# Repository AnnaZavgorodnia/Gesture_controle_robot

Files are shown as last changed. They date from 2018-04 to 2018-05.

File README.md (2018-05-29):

# [Gesture_controle_robot](https://docs.google.com/document/d/1Y3_o9-OHFA1TtbafuHDtEz-drBp5un7FaggCU-9pLuw/edit)

  [Presentation Demo](https://docs.google.com/presentation/d/1enwyCBrnziEQhG71OeViNuP6OWcIG7AhS4pcQQWysCI/edit#slide=id.p13)
=======
  
  [Sprint #1](https://docs.google.com/presentation/d/1gFuyWH_bSRb89d4ghf7KW_kzOMq5I33SIoRrUrdaeKE/edit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)
===
  [Final sprint](https://1drv.ms/p/s!Ak92ZIq3Xi4bhtIZYXvks18J-Bw90Q)
===
  [Product backlog](https://drive.google.com/open?id=1zqYQrvDOsD2uEPSQYLFSE-jVBQk2PwaP)
======  
  [Documentation(h/w docs)](https://drive.google.com/open?id=1KyRusOho9I7-eRYo6nIfgNrfgis1kgnL)
======
  -Результаты планування - https://docs.google.com/spreadsheets/d/1boEYJevMC1zRHPI-ftn7vFzjddT5e-UomYMGgAPh5HQ/edit#gid=1566601514

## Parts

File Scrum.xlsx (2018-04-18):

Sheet: Product Backlog
ID | Name | Priority | Estimate | How to Demo | Notes
1 | Зібрати проект + дизайн |  | 4
2 | Робо-платформа може переміщуватися вперед - назад | 1 | 2 | Прототип рухається у цих напрямках
3 | Робо-платформа може розвертатися вліво - вправо | 2 | 3
4 | За допомогою нахилу руки вперед - назад -вліво - вправо можна керувати рухом робо-платформи | 3 | 6 | Нахиляємо руку з датчиком і прототип рухається за напрямком
5 | Робо-платформа може переміщувати предмети не великої маси (для цього зроблена спеціальна платформа) | 4 | 1 | Переміщуємо предмети на деяку відстань / відео-ролик
7 | Робо-платформа зупиняється (не рухається вперед), якщо перед нею перешкода (назад може рухатися). | 5 | 3 | Вмикаємо робота, ставимо перешкоду й напраляємо рух робота на неї - він не рухаэться впред
8 | Робо-платформа може рухатися по заданому щляху (наприклад 2 м вліво та 2 вперед, та ін.) | 6 | 8 | Задаємо шлях, й робот рухається відповідно до шляху
9 | Робо-платформа має ліхтарики "фари" | 1 | 1 | Демонструємо світіння ліхтариків робота
10 | Робо-платформа має RGB-індикатор який приймає різні кольори в залежності від стану/ситуації | 2 | 1 | Демонструємо зміну кольору індикатора в залежності від стану/наявності перешкоди
13 | Робо-платформа може зберігати в памьяті маршрут руху й потім по сигналу відтворювати його. | 5 |  | Вмикаємо запис і рухаємо робота. Потім ставимо його на початкове положення і вмикаємо відтворення
14 | Робо-платформа може вимірювати відстань до об'єктів що знаходяться зліва і зправа від неї (датчик постійно рухається вліво - вправо) | 7 |  | Демонструємо роботу датчика
17 | Під час відтворення маршрутів робот огинає перешкоди й не втрачаючи прицьому точність руху | 8 |  | Демонструємо проходження маршруту з перешкодами
19 | Швидкість руху змінюється в залежності від кута нахилу руки | 9 |  | Нахиляємо руку на різний кут і спострерігаємо за швидкісю робота
24 | Створювати й задавати маршрути можна за допомогою перчатки, також перемикати режими й вести керування (за необхідності) | 12
11 | Нахили вперед і вліво / вперед і вправо - відповідний рух робо-платформи | 3 |  | Нахиляємо руку з датчиком і прототип рухається за напрямком | Треба поміркувати над доцільністю
12 | Нахили вліво і назад / вправо і назад - відповідний рух робо-платформи | 4 |  | Нахиляємо руку з датчиком і прототип рухається за напрямком | Треба поміркувати над доцільністю
15 | Кожним з 4х колес можна керувати роздільно (вони не зв'язані попарно) й задавати напрямок | 7 |  | Демонструємо що коли 1е колесо по один бік рухається 2ге по той же бік може стояти. Преше в одному напрямку, інше - в протилежному. | Треба поміркувати над доцільністю
16 | Робо платформа має камеру й може записувати відео під час руху | 6 |  | Рухаємо робота, записуємо відео і потім демонструємо записане відео
18 | Ліхтарики вмикаються якщо стає темно | 13 |  | Перекриваємо датчик світла - вмикаються ліхтарики
20 | Камера рухається вверх - вниз | 8
21 | Камера рухається вліво - вправо | 10
22 | Відео з камери можна переглядати на телефоні | 9
23 | Відео з камери можна переглядати на телефоні у VR й рухати камер в залежності від положення телефону у VR-окулярах | 11

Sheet: Sprint Plans
Спринт 1
Ціль спринта | Підготувати базову версію проекту
Список та доступність учасників | Всі учасники будуть працювати над проектом
Чітко визначена дата і час проведення демонстрації спринта | 20 Березня 2018 13:20 Аудиторія 76-14
Визначений час і місце для проведення щоденного скраму | О 20:00 вечора в Телеграмі
Спринт 2
Ціль спринта | Підготувати фінальну версію проекту
Список та доступність учасників | Всі учасники будуть працювати над проектом
Чітко визначена дата і час проведення демонстрації спринта | 24 Квітня 2018 13:20 Аудиторія 76-14
Визначений час і місце для проведення щоденного скраму | О 20:00 вечора в Телеграмі

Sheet: Sprint 1 Backlog
1 | 25.02.2018 | Зробити ескіз проекту (The Somberlain) | 1
2 | 2018-02-26 | Створити документацію для проекту (Всі) | 1
3 | 2018-02-25 | Створити схеми (The Somberlain) | 0.5
4 | 2018-03-03 | Купить всі необхідні деталі (Витя) | 1
5 | 2018-03-07 | Створити каркас робо-платформи (Аня Городченко) | 1
6 | 2018-03-10 | Зібрати проект (під'єднати всі деталі) (Всі разом) | 1
7 | 2018-03-01 | Налаштувати роботу двигунів (вперед - назад) (Свя.) | 1
8 | 2018-03-01 | Налаштувати роботу двигунів (вліво - вправо) | 1
9 | 2018-03-07 | Зібрати "перчатку" для керування роботом (Аня Завгородня) | 1
10 | 2018-03-07 | Налаштувати акселерометр та гіроскоп (Аня Завгородня)
11 | 2018-03-08 | Налаштувати обмін данними між роботом і "перчаткою" (The Somberlain) | 2
12 | 2018-01-08 | Налаштувати керування роботом положенням руки | 3
13 |  | Зробить дизайн перчатки (Витя) | 2
14 |  | Розробити дизайн робо-платформи (Ані) | 1
15 |  | Створити "багажник" для предметів | 2
16 |  | Приєднати та налаштувати датчик відстані | 1
17 |  | Налаштувати рух робота в залежності від даних датчика відстані | 2
18 |  | Дослідити рух та повороти робота та знайти оптимальні значення при яких змінювати рух (закінчувати поворот/припиняти рух в цьому напрямку) | 3
19 |  | Написати код методів руху на n - метрів | 2
20 |  | Налаштувати рух за заданим маршрутом | 3
21 |  | Робо-платформа має ліхтарики "фари" | 1
22 |  | Встановити ліхтарики й налаштувати Їх роботу | 1
23 |  | Робо-платформа має RGB-індикатор який приймає різні кольори в залежності від стану/ситуації | 2
24 |  | Підєднати світлодіод до робота й описати стани при яких буде змінюватися колір (налаштувати стани) | 2
25 |  | Налаштувати зміну колькору в залежності від стану | 2
26 |  | Тестування всіх можливостей проекту
27 |  | Усунення всіх виявлених на тестуванні багів

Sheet: Sprint 2 Backlog
# | Task | Doer | Difficulty | *Estimate (hours) | Priority | Data of statrting | Week
1 | Налаштувати рух робота в залежності від даних датчика відстані (який не рухається) | Свят. | Medium | 2 | 1 | - | 1
2 | Дослідити рух та повороти робота та знайти оптимальні значення при яких змінювати рух (закінчувати поворот/припиняти рух в цьому напрямку) |  |  |  |  |  | -
3 | Написати код методів руху за напрямком та тривалістю | Аня (Гор.) +/ Аня (Завг.) | Easy | 0.5 | 3 |  | 1
4 | Налаштувати рух за заданим маршрутом | Свят. | Medium | 5 | 3 |  | 1
5 | Встановити ліхтарики й налаштувати їх роботу | Аня (Гор.) + Аня (Завг.) | Medium | 3 | 6 |  | 1
6 | Описати стани при яких буде змінюватися колір RGB-світлодіода | Свят. | Medium | - | - | - | 1
7 | Підєднати світлодіод до робота та налаштувати зміну колькору світлодіода в залежності від стану | Аня (Завг.) | Medium | 3 | 6 |  | 1-2
8 | Реалізвати запис пройденого маршруту (у динамічний vector<>) а потім відтворення його з пам'яті | Аня (Завг.) | Medium | 5 | 5 |  | 2
9 | Підєднати сервомотор до робота, прикріпити до нього датчик відстані | Свят. / Аня (Гор.) | Easy | 1 | 2 |  | 2
10 | Налаштувати вічні повороти датчика (на 90 град.) з зупинками в положеннях ліво-прямо-право | Свят. | Medium | 2 | 2 |  | 2
11 | Налаштувати отримання даних за датчика відстані в положеннях Ліво-Прямо-Право | Свят. | Medium | 2 | 2 |  | 2
12 | Створити алгоритм огинання перешкод на основі даних датчика відстані | Свят. | Hard | 10 | 2 |  | 2
13 | Оптимізувати цей алгоритм для збереження точності руху за маршрутом (якщо ми повернули вліво щоб обминути перешкоду, то оминувши перешкоду треба знову стати на шлях й здійснити запланований маршрут) | Свят. | Hard | 8 | 4 |  | 2
14 | Налаштувати зміну швидкосты руху в залежності від кута нахилу руки |  |  |  |  |  | -
15 | Налаштувати створення маршрутів за допомогою жестів руки й передачі їх роботу | Свят. + Аня (Завг.) | Hard | 10 | 5 |  | 3
16 | Налаштувати перемикання режимів за допомогою кнопки на перчатці (+миганя фарами при активуванні режиму) | Свят. +/ Аня (Гор.) +/ Вітя | Medium | 5 | 6 |  | 3
 | Additional:
17 | Створити дизайн перчатки | Вітя | Medium | ? |  | - | 1
18 | Приєднати та налаштувати роботу кнопок на перчатці та на роботі | Вітя | Medium | 4 | 6 |  | 1
19 | Створити презентацію та відео-ролик про проект | Свят. + Даня | Hard | ~ | 1 |  | 1-2-3
20 | Створити дизайн робота | ? | Hard | ~ |  |  | ?
 | Не обов'язково робити |  | Total: | 58
 | Вже зроблено
 | В процесі
 | Виконання задачі = виконання задачі + тестування = 100% коректно працюючий (без багів, бажано) функціонал
 | * - it's MAX value (max that can be). Real time can me less then it.

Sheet: Режими
 | Всі режими після запуску, послідовним переключенням фар n-раз з однієї на іншу показують номер активованого режиму |  | Переключення режимів:
№ | Режим |  | 1.Фари вимикаються
0 | Пошук доступного каналу, налаштування та зєднання з перчаткою | Starting | 2. Вмикається ліва фара
1 | Управління роботом за допомогою руки (без обминання перешкод) | HandDriveDetourOff | 3. Якщо режим >= 2 вимикається ліва і вмикається права фара
 | Машина в русі - Синій |  | 4. Якщо режим >= 3 вимикається права і вмикається ліва фара
 | Очікування - Зелений |  | 5. Якщо режим >= 4 вимикається ліва і вмикається права фара
 |  |  | 6. Якщо режим >= 5 вимикається права і вмикається ліва фара
2 | Управління роботом за допомогою руки (з обминанням перешкод) | HandDriveDetourOn | 7. Якщо режим >= 6 вимикається ліва і вмикається права фара
 | Рух, перешкод немає - Синій |  | 8. Якщо режим == 7 вимикається права і вмикається ліва фара
 | Очікування, перешкод немає - Зелений |  | 9. Вимикаються обидві фари
 | Є перешкоди - Червоний |  | 10. Вмикаються обидві фари
3 | Запис маршруту за руху робота (при цьому він керується рукою) | HandDriveRouteRecording | 0. Пошук доступного каналу, налаштування та зєднання з перчаткою:
 | Синій завжди |  | Вмикається червоний
 |  |  | Сканування доступних каналів - Синій
 |  |  | Доступний канал знайдено - Зелений
 |  |  | Відправка знайденого каналу на перчатку
4 | Перевірка створеного (чи записаного) маршруту | RouteCheck | Налаштування каналу на пречатці
 | Послідовно (за маршрутом) вмикаются і вимикаються (на деякий час - згідно з маршрутом) світлодіоди: |  | Надходження підтвердження з перчатки (по знайденому каналу)
 | Фари - Вперед |  | Вимикається різнокольоровий світлодіод
 | Червоний - Назад |  | Вмикається режим #1
 | Синій - Вліво
 | Зелений - Вправо |  | Що представляє собою маршрут:
 | NONE - Світлодіод і фари вимкнені |  | Послідовність пар "напрямок-тривалість(час)" (vector<>)
 |  |  | Напрямки: Forward, Backward, Left, Right or NONE
5 | Створення нового маршруту за допомогою жестів руки | HandDriveRouteCreating | Тривалість: час в мілісекундах (1с = 1000 мс)
 | Залежно від сигналу який поступає з перчатки (напрямок руху) вмикаються й вимикаються (коли "NONE") світловіоди: |  | Наприклад:
 | Фари - Вперед |  | [1] {Forward, 2000}
 | Червоний - Назад |  | [2] {NONE, 500}
 | Синій - Вліво |  | [3] {Left, 1300}
 | Зелений - Вправо |  | [4] {BackWard, 1500}
 |  |  | [5] {NONE, 400}
6 | Рух за заданим маршрутом (без обминання перешкод) | DriveByRouteDetourOff | [6] {Right, 2500}
 | Машина в русі - Синій
 | Очікування - Зелений
7 | Рух за заданим маршрутом (з обминанням перешкод) | DriveByRouteDetourOn
 | Рух, перешкод немає - Синій
 | Очікування, перешкод немає - Зелений
 | Є перешкоди - Червоний

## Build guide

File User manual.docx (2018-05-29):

# Gesture Controlled Robot

Рік випуску: 2018
Версія: 2.0.5
Розробник: Enigma
Платформа: Arduino

Апартні компоненти що були використані при розробці:

1. Arduino Uno
2. Arduino Nano
3. Радіо-модуль NRF24L01+ 2.4 ГГц х2
4. Акселерометр та гіроскоп MPU-6050 модуль 6DOF
5. Драйвер чотрьох двигунів L298N
6. Електромотор x4
7. Дальномір Ultrasonic HC-SR04 x2
8. Світлодіоди
9. Елементи живлення

Робот має 2 режими роботи: «керування рукою» та «обминання перешкод»

1. Режим керування рукою

Для цього режиму потрібно перевірити чи підключені правильно такі піни:

- IN1 (Motor Driver) – D5 (Arduino Uno)
- ENA (Motor Driver) – D10 (Arduino Uno)
- MOSI (Radio Module) – D11 (Arduino Uno)

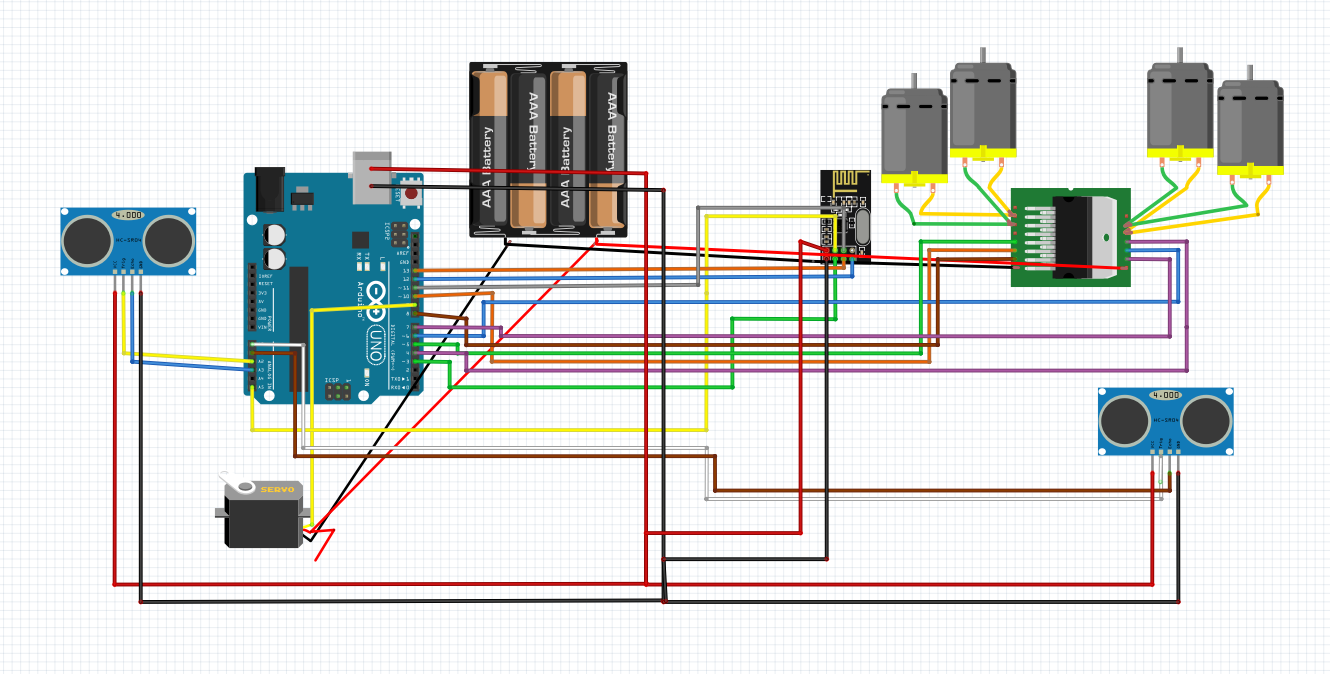
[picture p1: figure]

- MISO (Radion Module) – D12 (Arduino Uno)

Далі необхідно в коді, переключити режим на “Hand Control”.

У файлі robot.ino розкоментувати строку 22: « // cur_mode = HandControl;»,Та закоментувати строку 25: « // cur_mode = Detour; ».

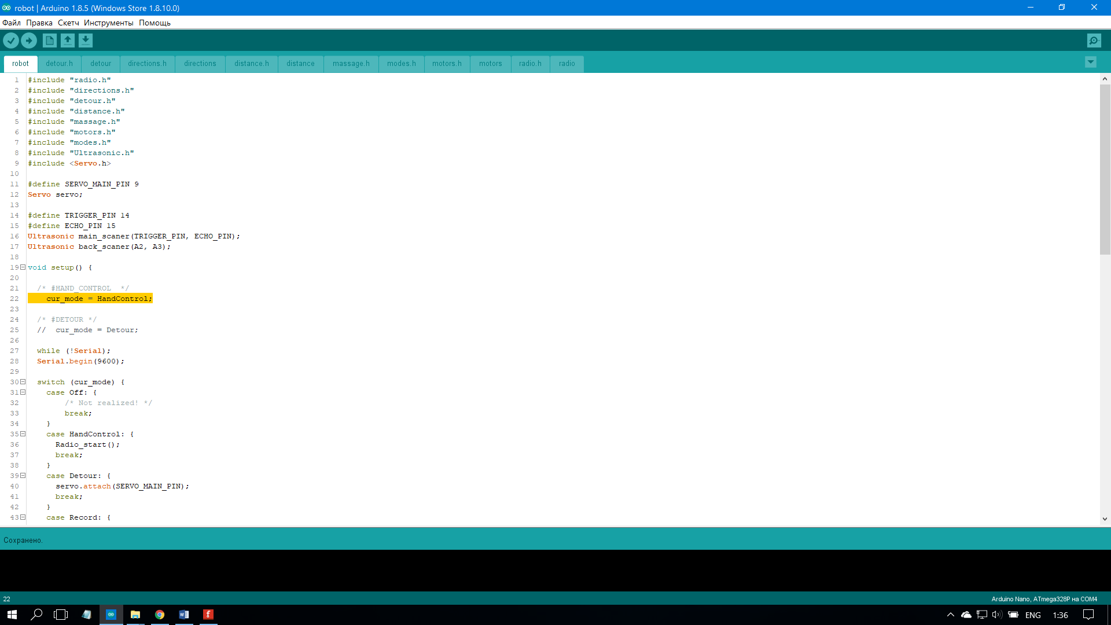
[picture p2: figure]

#### Завантаження коду на плату Arduino Uno

Для завантаження коду на плату необхідно завантажити Arduino IDE за посиланням (https://github.com/pppiproject/ThreeAxesGang/blob/master/www.arduino.cc/en/Main/Software)
Після встановлення програми, підключіть плату до комп'ютера за допомогою USB кабеля.
Натисність кнопку [Upload] або (ctrl + U) - цим програма завантажиться до плати.

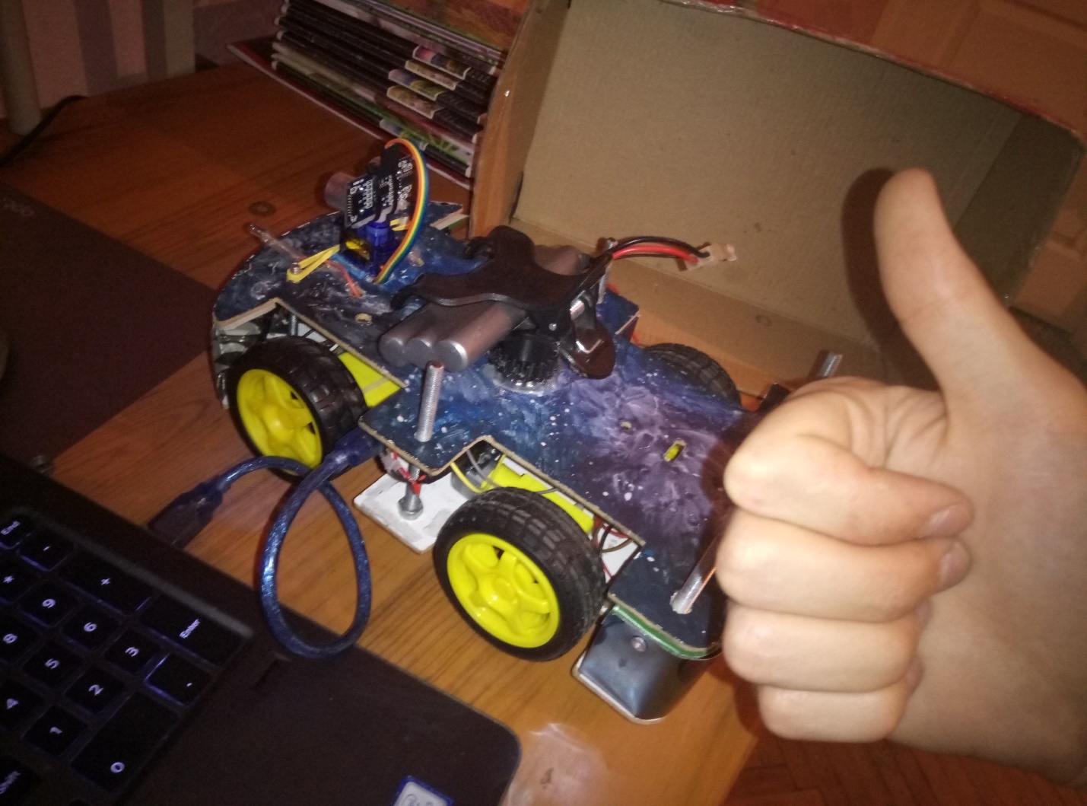
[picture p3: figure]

Для «перчатки» код вже встановлений й не змінюється ніколи. Він знаходится у папці hand –> файл hand.ino.

Спочатку підєднуємо живлення до робота, всовуючи 2 провідки робота, червоний та чорний у відповідні слоти на коннекторі аккумуляторів (повинні ввімкнутися ліхтарики). Потім одягаємо «перчатку» й підключаємо батарейку «крона».

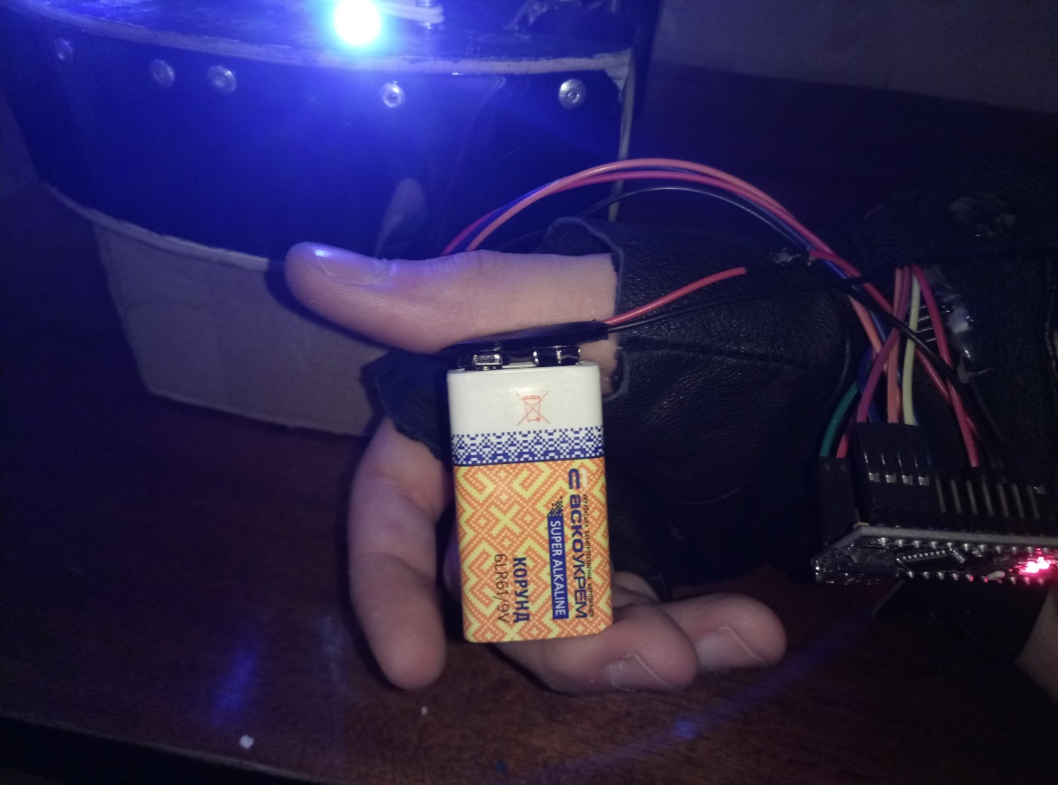
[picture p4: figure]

Все, робот готовий до керування.

Для керування роботом, нахиляй руку в будь-яку зі сторін: вліво-вправо-вперед-назад й робот поїде в ту строну. В положенні рівноваги робот зупиняється.

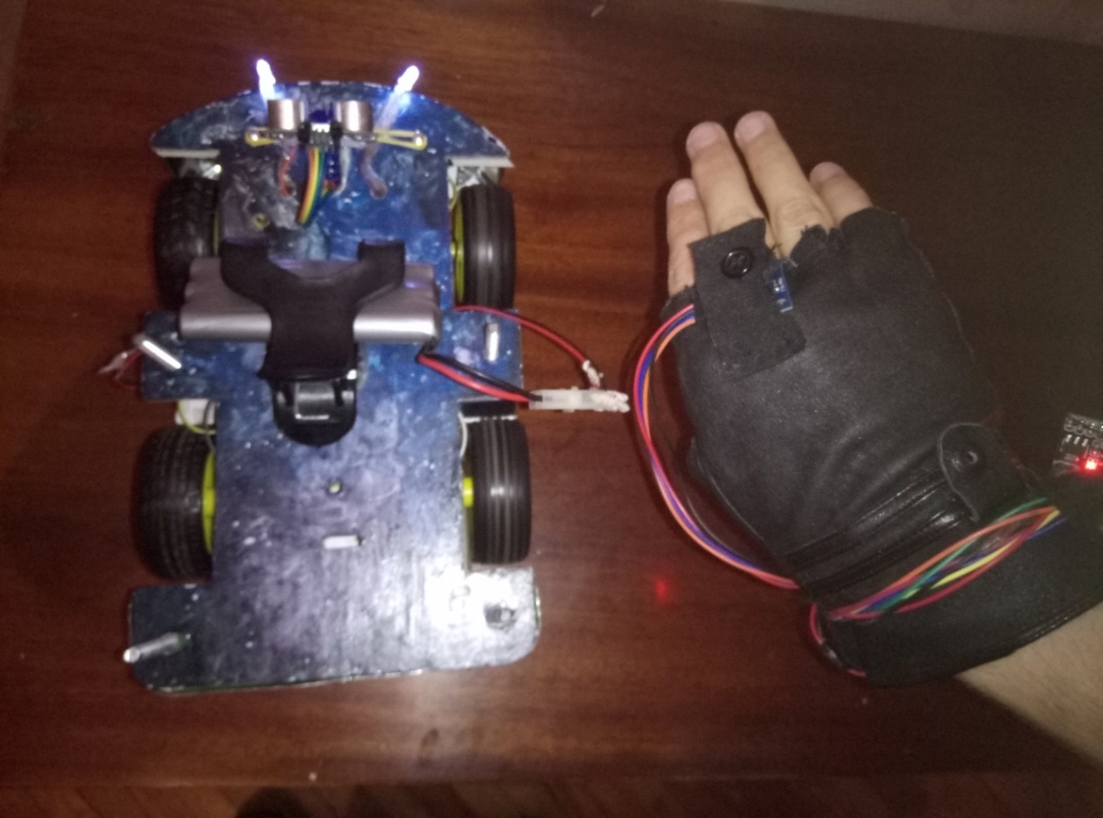
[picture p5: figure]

Якщо чомусь не почало працювати: перезапустіть одночасно перчатку й робот, або змініть канал радіо-зв’язку (robot -> radio.ino -> 8-ма строка «radio.setChannel(120);», де замість 120 впишіть інше значення 0-125 (в коді перчатки це строка 779, змініть як в коді робота так і в коді перчатки). (Інщі прилади, такі як Wi-Fi, Bluetooth, побутова техніка, можуть заважати передачі даних на цьому каналі).

2. Обминання перешкод

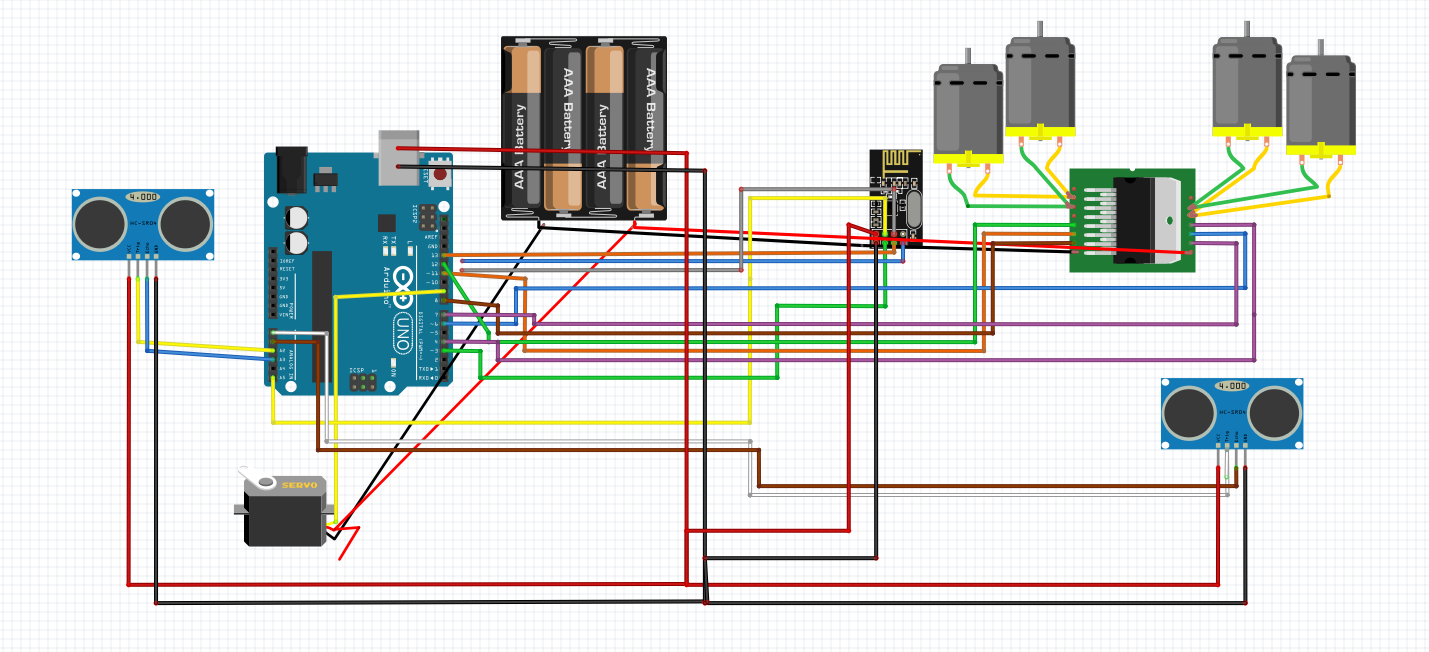
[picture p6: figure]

Для цього режиму потрібно перевірити чи підключені правильно такі піни:

- IN1 (Motor Driver) – D12 (Arduino Uno)
- ENA (Motor Driver) – D11 (Arduino Uno)

Далі необхідно в коді, переключити режим на “Detour”.

У файлі robot.ino закоментувати строку 22: « // cur_mode = HandControl;»,

Та розкоментувати строку 25: « // cur_mode = Detour; ».

Вмикаємо та граємось.

Цей режим не може нормально працювати в усіх випадках, так як використовується УЛЬТРАЗВУКОВИЙ дальномір, й звук відбивається від похилих поверхонь не точно в ту сторону, з якої він прийшов (він відбивається від поверхні під кутом, який дорівнює куту падіння, але з іншої сторони. Тому чим блище напрямок звука до перпендикуляра до поверхні, тим точніше виміри).

Алгоритм обминання перешкод:

Є декілька рівнів відстані:

Critical 1-5 cm,

Very close 6 – 15 cm, - лише розворот на місці або рух задом чи поворот назад-ліво (чи назад-право)

Close 16-25 cm, - можна робити поворот під кутом 45 град. (вперед-вліво чи вперед-вправо)

Average 26-40 cm – вперед, чи поворот під кут. 45 град.

Long Away 41-60 cm. - вперед

Датчик зчитує відстань до перешкоди спереду й на основі рівня отриманої відстані виконується логіка. Під час логіки додатково можуть вимірюватися відстані до перешкод під іншими кутами.

Робот може виконувати такі рухи (в залежності від таблиці отриманих відстаней)

1. Впред
2. Назад
3. Вперед-Вліво (Вліво під кут. 45 град.)
4. Вперед-Вправо (Вправо під кут. 45 град.)
5. Вліво на місці
6. Вправо на місці
7. Назад-Вліво
8. Назад-Вправо

Тобто алгоритм має вхідні данні – таблиця відстаней (0 град. – 24 см, 45 град. – 57 см., 90 град. – 53 см, 135 град. – 21 см. , 180 град. – 57 см. Назад – 70 см.) й приймає рішення (в даному випадку продовжувати рухатися прямо, поки відстань не стане < 41 см).

Код алгоритму знаходится в файлі detour.ino – метод “new_algorithm();”.

Весь код знаходится в репозиторії в папці «code».

Зв’язок по технічним питанням – Telegram @cyber_script

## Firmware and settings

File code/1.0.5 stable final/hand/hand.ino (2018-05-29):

#include <SPI.h>          // библиотека для работы с шиной SPI
#include "nRF24L01.h"     // библиотека радиомодуля
#include "RF24.h"         // ещё библиотека радиомодуля
#include <Wire.h>

RF24 radio(9, 10); // "создать" модуль на пинах 9 и 10 Для Уно
//RF24 radio(9,53); // для Меги

byte address[][6] = {"1Node", "2Node", "3Node", "4Node", "5Node", "6Node"}; //возможные номера труб

const byte rxAddr[6] = "00001";
//
//byte SWITCH_OFF_BUTTON = 2;
//
//pinMode(SWITCH_OFF_BUTTON, OUTPUT);
//  attachInterrupt(0, blink, CHANGE);

enum InputTypes {
  DIR_NONE,
  DIR_FORWARD,
  DIR_BACKWARD,
  DIR_LEFT,
  DIR_RIGHT,
  SHANGE_MODE,
  SWITCH_OFF,
  SWITCH_ON
};

byte robo_speed = 0;;

byte dir = DIR_NONE;

// axelerometer + gyroscope MPU-6050
// Register names according to the datasheet.
// According to the InvenSense document 
// "MPU-6000 and MPU-6050 Register Map 
// and Descriptions Revision 3.2", there are no registers
// at 0x02 ... 0x18, but according other information 
// the registers in that unknown area are for gain 
// and offsets.
// 
#define MPU6050_AUX_VDDIO          0x01   // R/W
#define MPU6050_SMPLRT_DIV         0x19   // R/W
#define MPU6050_CONFIG             0x1A   // R/W
#define MPU6050_GYRO_CONFIG        0x1B   // R/W
#define MPU6050_ACCEL_CONFIG       0x1C   // R/W
#define MPU6050_FF_THR             0x1D   // R/W
#define MPU6050_FF_DUR             0x1E   // R/W
#define MPU6050_MOT_THR            0x1F   // R/W
#define MPU6050_MOT_DUR            0x20   // R/W
#define MPU6050_ZRMOT_THR          0x21   // R/W
#define MPU6050_ZRMOT_DUR          0x22   // R/W
#define MPU6050_FIFO_EN            0x23   // R/W
#define MPU6050_I2C_MST_CTRL       0x24   // R/W
#define MPU6050_I2C_SLV0_ADDR      0x25   // R/W
#define MPU6050_I2C_SLV0_REG       0x26   // R/W
#define MPU6050_I2C_SLV0_CTRL      0x27   // R/W
#define MPU6050_I2C_SLV1_ADDR      0x28   // R/W
#define MPU6050_I2C_SLV1_REG       0x29   // R/W
#define MPU6050_I2C_SLV1_CTRL      0x2A   // R/W
#define MPU6050_I2C_SLV2_ADDR      0x2B   // R/W
#define MPU6050_I2C_SLV2_REG       0x2C   // R/W
#define MPU6050_I2C_SLV2_CTRL      0x2D   // R/W
#define MPU6050_I2C_SLV3_ADDR      0x2E   // R/W
#define MPU6050_I2C_SLV3_REG       0x2F   // R/W
#define MPU6050_I2C_SLV3_CTRL      0x30   // R/W
#define MPU6050_I2C_SLV4_ADDR      0x31   // R/W
#define MPU6050_I2C_SLV4_REG       0x32   // R/W
#define MPU6050_I2C_SLV4_DO        0x33   // R/W
#define MPU6050_I2C_SLV4_CTRL      0x34   // R/W
#define MPU6050_I2C_SLV4_DI        0x35   // R  
#define MPU6050_I2C_MST_STATUS     0x36   // R
#define MPU6050_INT_PIN_CFG        0x37   // R/W
#define MPU6050_INT_ENABLE         0x38   // R/W
#define MPU6050_INT_STATUS         0x3A   // R  
#define MPU6050_ACCEL_XOUT_H       0x3B   // R  
#define MPU6050_ACCEL_XOUT_L       0x3C   // R  
#define MPU6050_ACCEL_YOUT_H       0x3D   // R  
#define MPU6050_ACCEL_YOUT_L       0x3E   // R  
#define MPU6050_ACCEL_ZOUT_H       0x3F   // R  
#define MPU6050_ACCEL_ZOUT_L       0x40   // R  
#define MPU6050_TEMP_OUT_H         0x41   // R  
#define MPU6050_TEMP_OUT_L         0x42   // R  
#define MPU6050_GYRO_XOUT_H        0x43   // R  
#define MPU6050_GYRO_XOUT_L        0x44   // R  
#define MPU6050_GYRO_YOUT_H        0x45   // R  
#define MPU6050_GYRO_YOUT_L        0x46   // R  
#define MPU6050_GYRO_ZOUT_H        0x47   // R  
#define MPU6050_GYRO_ZOUT_L        0x48   // R  
#define MPU6050_EXT_SENS_DATA_00   0x49   // R  
#define MPU6050_EXT_SENS_DATA_01   0x4A   // R  
#define MPU6050_EXT_SENS_DATA_02   0x4B   // R  
#define MPU6050_EXT_SENS_DATA_03   0x4C   // R  
#define MPU6050_EXT_SENS_DATA_04   0x4D   // R  
#define MPU6050_EXT_SENS_DATA_05   0x4E   // R  
#define MPU6050_EXT_SENS_DATA_06   0x4F   // R  
#define MPU6050_EXT_SENS_DATA_07   0x50   // R  
#define MPU6050_EXT_SENS_DATA_08   0x51   // R  
#define MPU6050_EXT_SENS_DATA_09   0x52   // R  
#define MPU6050_EXT_SENS_DATA_10   0x53   // R  
#define MPU6050_EXT_SENS_DATA_11   0x54   // R  
#define MPU6050_EXT_SENS_DATA_12   0x55   // R  
#define MPU6050_EXT_SENS_DATA_13   0x56   // R  
#define MPU6050_EXT_SENS_DATA_14   0x57   // R  
#define MPU6050_EXT_SENS_DATA_15   0x58   // R  
#define MPU6050_EXT_SENS_DATA_16   0x59   // R  
#define MPU6050_EXT_SENS_DATA_17   0x5A   // R  
#define MPU6050_EXT_SENS_DATA_18   0x5B   // R  
#define MPU6050_EXT_SENS_DATA_19   0x5C   // R  
#define MPU6050_EXT_SENS_DATA_20   0x5D   // R  
#define MPU6050_EXT_SENS_DATA_21   0x5E   // R  
#define MPU6050_EXT_SENS_DATA_22   0x5F   // R  
#define MPU6050_EXT_SENS_DATA_23   0x60   // R  
#define MPU6050_MOT_DETECT_STATUS  0x61   // R  
#define MPU6050_I2C_SLV0_DO        0x63   // R/W
#define MPU6050_I2C_SLV1_DO        0x64   // R/W
#define MPU6050_I2C_SLV2_DO        0x65   // R/W
#define MPU6050_I2C_SLV3_DO        0x66   // R/W
#define MPU6050_I2C_MST_DELAY_CTRL 0x67   // R/W
#define MPU6050_SIGNAL_PATH_RESET  0x68   // R/W
#define MPU6050_MOT_DETECT_CTRL    0x69   // R/W
#define MPU6050_USER_CTRL          0x6A   // R/W
#define MPU6050_PWR_MGMT_1         0x6B   // R/W
#define MPU6050_PWR_MGMT_2         0x6C   // R/W
#define MPU6050_FIFO_COUNTH        0x72   // R/W
#define MPU6050_FIFO_COUNTL        0x73   // R/W
#define MPU6050_FIFO_R_W           0x74   // R/W
#define MPU6050_WHO_AM_I           0x75   // R


// Defines for the bits, to be able to change 
// between bit number and binary definition.
// By using the bit number, programming the sensor 
// is like programming the AVR microcontroller.
// But instead of using "(1<<X)", or "_BV(X)", 
// the Arduino "bit(X)" is used.
#define MPU6050_D0 0
#define MPU6050_D1 1
#define MPU6050_D2 2
#define MPU6050_D3 3
#define MPU6050_D4 4
#define MPU6050_D5 5
#define MPU6050_D6 6
#define MPU6050_D7 7

// AUX_VDDIO Register
#define MPU6050_AUX_VDDIO MPU6050_D7  // I2C high: 1=VDD, 0=VLOGIC

// CONFIG Register
// DLPF is Digital Low Pass Filter for both gyro and accelerometers.
// These are the names for the bits.
// Use these only with the bit() macro.
#define MPU6050_DLPF_CFG0     MPU6050_D0
#define MPU6050_DLPF_CFG1     MPU6050_D1
#define MPU6050_DLPF_CFG2     MPU6050_D2
#define MPU6050_EXT_SYNC_SET0 MPU6050_D3
#define MPU6050_EXT_SYNC_SET1 MPU6050_D4
#define MPU6050_EXT_SYNC_SET2 MPU6050_D5

// Combined definitions for the EXT_SYNC_SET values
#define MPU6050_EXT_SYNC_SET_0 (0)
#define MPU6050_EXT_SYNC_SET_1 (bit(MPU6050_EXT_SYNC_SET0))
#define MPU6050_EXT_SYNC_SET_2 (bit(MPU6050_EXT_SYNC_SET1))
#define MPU6050_EXT_SYNC_SET_3 (bit(MPU6050_EXT_SYNC_SET1)|bit(MPU6050_EXT_SYNC_SET0))
#define MPU6050_EXT_SYNC_SET_4 (bit(MPU6050_EXT_SYNC_SET2))
#define MPU6050_EXT_SYNC_SET_5 (bit(MPU6050_EXT_SYNC_SET2)|bit(MPU6050_EXT_SYNC_SET0))
#define MPU6050_EXT_SYNC_SET_6 (bit(MPU6050_EXT_SYNC_SET2)|bit(MPU6050_EXT_SYNC_SET1))
#define MPU6050_EXT_SYNC_SET_7 (bit(MPU6050_EXT_SYNC_SET2)|bit(MPU6050_EXT_SYNC_SET1)|bit(MPU6050_EXT_SYNC_SET0))

// Alternative names for the combined definitions.
#define MPU6050_EXT_SYNC_DISABLED     MPU6050_EXT_SYNC_SET_0
#define MPU6050_EXT_SYNC_TEMP_OUT_L   MPU6050_EXT_SYNC_SET_1
#define MPU6050_EXT_SYNC_GYRO_XOUT_L  MPU6050_EXT_SYNC_SET_2
#define MPU6050_EXT_SYNC_GYRO_YOUT_L  MPU6050_EXT_SYNC_SET_3
#define MPU6050_EXT_SYNC_GYRO_ZOUT_L  MPU6050_EXT_SYNC_SET_4
#define MPU6050_EXT_SYNC_ACCEL_XOUT_L MPU6050_EXT_SYNC_SET_5
#define MPU6050_EXT_SYNC_ACCEL_YOUT_L MPU6050_EXT_SYNC_SET_6
#define MPU6050_EXT_SYNC_ACCEL_ZOUT_L MPU6050_EXT_SYNC_SET_7

// Combined definitions for the DLPF_CFG values
#define MPU6050_DLPF_CFG_0 (0)
#define MPU6050_DLPF_CFG_1 (bit(MPU6050_DLPF_CFG0))
#define MPU6050_DLPF_CFG_2 (bit(MPU6050_DLPF_CFG1))
#define MPU6050_DLPF_CFG_3 (bit(MPU6050_DLPF_CFG1)|bit(MPU6050_DLPF_CFG0))
#define MPU6050_DLPF_CFG_4 (bit(MPU6050_DLPF_CFG2))
#define MPU6050_DLPF_CFG_5 (bit(MPU6050_DLPF_CFG2)|bit(MPU6050_DLPF_CFG0))
#define MPU6050_DLPF_CFG_6 (bit(MPU6050_DLPF_CFG2)|bit(MPU6050_DLPF_CFG1))
#define MPU6050_DLPF_CFG_7 (bit(MPU6050_DLPF_CFG2)|bit(MPU6050_DLPF_CFG1)|bit(MPU6050_DLPF_CFG0))

// Alternative names for the combined definitions
// This name uses the bandwidth (Hz) for the accelometer,
// for the gyro the bandwidth is almost the same.
#define MPU6050_DLPF_260HZ    MPU6050_DLPF_CFG_0
#define MPU6050_DLPF_184HZ    MPU6050_DLPF_CFG_1
#define MPU6050_DLPF_94HZ     MPU6050_DLPF_CFG_2
#define MPU6050_DLPF_44HZ     MPU6050_DLPF_CFG_3
#define MPU6050_DLPF_21HZ     MPU6050_DLPF_CFG_4
#define MPU6050_DLPF_10HZ     MPU6050_DLPF_CFG_5
#define MPU6050_DLPF_5HZ      MPU6050_DLPF_CFG_6
#define MPU6050_DLPF_RESERVED MPU6050_DLPF_CFG_7

// GYRO_CONFIG Register
// The XG_ST, YG_ST, ZG_ST are bits for selftest.
// The FS_SEL sets the range for the gyro.
// These are the names for the bits.
// Use these only with the bit() macro.
#define MPU6050_FS_SEL0 MPU6050_D3
#define MPU6050_FS_SEL1 MPU6050_D4
#define MPU6050_ZG_ST   MPU6050_D5
#define MPU6050_YG_ST   MPU6050_D6
#define MPU6050_XG_ST   MPU6050_D7

// Combined definitions for the FS_SEL values
#define MPU6050_FS_SEL_0 (0)
#define MPU6050_FS_SEL_1 (bit(MPU6050_FS_SEL0))
#define MPU6050_FS_SEL_2 (bit(MPU6050_FS_SEL1))
#define MPU6050_FS_SEL_3 (bit(MPU6050_FS_SEL1)|bit(MPU6050_FS_SEL0))

// Alternative names for the combined definitions
// The name uses the range in degrees per second.
#define MPU6050_FS_SEL_250  MPU6050_FS_SEL_0
#define MPU6050_FS_SEL_500  MPU6050_FS_SEL_1
#define MPU6050_FS_SEL_1000 MPU6050_FS_SEL_2
#define MPU6050_FS_SEL_2000 MPU6050_FS_SEL_3

// ACCEL_CONFIG Register
// The XA_ST, YA_ST, ZA_ST are bits for selftest.
// The AFS_SEL sets the range for the accelerometer.
// These are the names for the bits.
// Use these only with the bit() macro.
#define MPU6050_ACCEL_HPF0 MPU6050_D0
#define MPU6050_ACCEL_HPF1 MPU6050_D1
#define MPU6050_ACCEL_HPF2 MPU6050_D2
#define MPU6050_AFS_SEL0   MPU6050_D3
#define MPU6050_AFS_SEL1   MPU6050_D4
#define MPU6050_ZA_ST      MPU6050_D5
#define MPU6050_YA_ST      MPU6050_D6
#define MPU6050_XA_ST      MPU6050_D7

// Combined definitions for the ACCEL_HPF values
#define MPU6050_ACCEL_HPF_0 (0)
#define MPU6050_ACCEL_HPF_1 (bit(MPU6050_ACCEL_HPF0))
#define MPU6050_ACCEL_HPF_2 (bit(MPU6050_ACCEL_HPF1))
#define MPU6050_ACCEL_HPF_3 (bit(MPU6050_ACCEL_HPF1)|bit(MPU6050_ACCEL_HPF0))
#define MPU6050_ACCEL_HPF_4 (bit(MPU6050_ACCEL_HPF2))
#define MPU6050_ACCEL_HPF_7 (bit(MPU6050_ACCEL_HPF2)|bit(MPU6050_ACCEL_HPF1)|bit(MPU6050_ACCEL_HPF0))

// Alternative names for the combined definitions
// The name uses the Cut-off frequency.
#define MPU6050_ACCEL_HPF_RESET  MPU6050_ACCEL_HPF_0
#define MPU6050_ACCEL_HPF_5HZ    MPU6050_ACCEL_HPF_1
#define MPU6050_ACCEL_HPF_2_5HZ  MPU6050_ACCEL_HPF_2
#define MPU6050_ACCEL_HPF_1_25HZ MPU6050_ACCEL_HPF_3
#define MPU6050_ACCEL_HPF_0_63HZ MPU6050_ACCEL_HPF_4
#define MPU6050_ACCEL_HPF_HOLD   MPU6050_ACCEL_HPF_7

// Combined definitions for the AFS_SEL values
#define MPU6050_AFS_SEL_0 (0)
#define MPU6050_AFS_SEL_1 (bit(MPU6050_AFS_SEL0))
#define MPU6050_AFS_SEL_2 (bit(MPU6050_AFS_SEL1))
#define MPU6050_AFS_SEL_3 (bit(MPU6050_AFS_SEL1)|bit(MPU6050_AFS_SEL0))

// Alternative names for the combined definitions
// The name uses the full scale range for the accelerometer.
#define MPU6050_AFS_SEL_2G  MPU6050_AFS_SEL_0
#define MPU6050_AFS_SEL_4G  MPU6050_AFS_SEL_1
#define MPU6050_AFS_SEL_8G  MPU6050_AFS_SEL_2
#define MPU6050_AFS_SEL_16G MPU6050_AFS_SEL_3

// FIFO_EN Register
// These are the names for the bits.
// Use these only with the bit() macro.
#define MPU6050_SLV0_FIFO_EN  MPU6050_D0
#define MPU6050_SLV1_FIFO_EN  MPU6050_D1
#define MPU6050_SLV2_FIFO_EN  MPU6050_D2
#define MPU6050_ACCEL_FIFO_EN MPU6050_D3
#define MPU6050_ZG_FIFO_EN    MPU6050_D4
#define MPU6050_YG_FIFO_EN    MPU6050_D5
#define MPU6050_XG_FIFO_EN    MPU6050_D6
#define MPU6050_TEMP_FIFO_EN  MPU6050_D7

// I2C_MST_CTRL Register
// These are the names for the bits.
// Use these only with the bit() macro.
#define MPU6050_I2C_MST_CLK0  MPU6050_D0
#define MPU6050_I2C_MST_CLK1  MPU6050_D1
#define MPU6050_I2C_MST_CLK2  MPU6050_D2
#define MPU6050_I2C_MST_CLK3  MPU6050_D3
#define MPU6050_I2C_MST_P_NSR MPU6050_D4
#define MPU6050_SLV_3_FIFO_EN MPU6050_D5
#define MPU6050_WAIT_FOR_ES   MPU6050_D6
#define MPU6050_MULT_MST_EN   MPU6050_D7
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
void loop() {
int error;
  double dT;
  accel_t_gyro_union accel_t_gyro;

  /*
  Serial.println(F(""));
  Serial.println(F("MPU-6050"));
  */
  
  // Read the raw values.
  error = read_gyro_accel_vals((uint8_t*) &accel_t_gyro);
  
  // Get the time of reading for rotation computations
  unsigned long t_now = millis();
   
/*
  Serial.print(F("Read accel, temp and gyro, error = "));
  Serial.println(error,DEC);
  

  // Print the raw acceleration values
  Serial.print(F("accel x,y,z: "));
  Serial.print(accel_t_gyro.value.x_accel, DEC);
  Serial.print(F(", "));
  Serial.print(accel_t_gyro.value.y_accel, DEC);
  Serial.print(F(", "));
  Serial.print(accel_t_gyro.value.z_accel, DEC);
  Serial.println(F(""));
*/ 

  // The temperature sensor is -40 to +85 degrees Celsius.
  // It is a signed integer.
  // According to the datasheet: 
  //   340 per degrees Celsius, -512 at 35 degrees.
  // At 0 degrees: -512 - (340 * 35) = -12412
/*  
  Serial.print(F("temperature: "));
  dT = ( (double) accel_t_gyro.value.temperature + 12412.0) / 340.0;
  Serial.print(dT, 3);
  Serial.print(F(" degrees Celsius"));
  Serial.println(F(""));
  

  // Print the raw gyro values.
  Serial.print(F("raw gyro x,y,z : "));
  Serial.print(accel_t_gyro.value.x_gyro, DEC);
  Serial.print(F(", "));
  Serial.print(accel_t_gyro.value.y_gyro, DEC);
  Serial.print(F(", "));
  Serial.print(accel_t_gyro.value.z_gyro, DEC);
  Serial.print(F(", "));
  Serial.println(F(""));
*/

  // Convert gyro values to degrees/sec
  float FS_SEL = 131;
  /*
  float gyro_x = (accel_t_gyro.value.x_gyro - base_x_gyro)/FS_SEL;
  float gyro_y = (accel_t_gyro.value.y_gyro - base_y_gyro)/FS_SEL;
  float gyro_z = (accel_t_gyro.value.z_gyro - base_z_gyro)/FS_SEL;
  */
  float gyro_x = (accel_t_gyro.value.x_gyro - base_x_gyro)/FS_SEL;
  float gyro_y = (accel_t_gyro.value.y_gyro - base_y_gyro)/FS_SEL;
  float gyro_z = (accel_t_gyro.value.z_gyro - base_z_gyro)/FS_SEL;
  
  
  // Get raw acceleration values
  //float G_CONVERT = 16384;
  float accel_x = accel_t_gyro.value.x_accel;
  float accel_y = accel_t_gyro.value.y_accel;
  float accel_z = accel_t_gyro.value.z_accel;
  
  // Get angle values from accelerometer
  float RADIANS_TO_DEGREES = 180/3.14159;
//  float accel_vector_length = sqrt(pow(accel_x,2) + pow(accel_y,2) + pow(accel_z,2));
  float accel_angle_y = atan(-1*accel_x/sqrt(pow(accel_y,2) + pow(accel_z,2)))*RADIANS_TO_DEGREES;
  float accel_angle_x = atan(accel_y/sqrt(pow(accel_x,2) + pow(accel_z,2)))*RADIANS_TO_DEGREES;

  float accel_angle_z = 0;
  
  // Compute the (filtered) gyro angles
  float dt =(t_now - get_last_time())/1000.0;
  float gyro_angle_x = gyro_x*dt + get_last_x_angle();
  float gyro_angle_y = gyro_y*dt + get_last_y_angle();
  float gyro_angle_z = gyro_z*dt + get_last_z_angle();
  
  // Compute the drifting gyro angles
  float unfiltered_gyro_angle_x = gyro_x*dt + get_last_gyro_x_angle();
  float unfiltered_gyro_angle_y = gyro_y*dt + get_last_gyro_y_angle();
  float unfiltered_gyro_angle_z = gyro_z*dt + get_last_gyro_z_angle();
  
  // Apply the complementary filter to figure out the change in angle - choice of alpha is
  // estimated now.  Alpha depends on the sampling rate...
  float alpha = 0.96;
  float angle_x = alpha*gyro_angle_x + (1.0 - alpha)*accel_angle_x;
  float angle_y = alpha*gyro_angle_y + (1.0 - alpha)*accel_angle_y;
  float angle_z = gyro_angle_z;  //Accelerometer doesn't give z-angle
  
  // Update the saved data with the latest values
  set_last_read_angle_data(t_now, angle_x, angle_y, angle_z, unfiltered_gyro_angle_x, unfiltered_gyro_angle_y, unfiltered_gyro_angle_z);
  
  // Send the data to the serial port
  /*
  Serial.print(F("DEL:"));              //Delta T
  Serial.print(dt, DEC);
  Serial.print(F("#ACC:"));              //Accelerometer angle
  Serial.print(accel_angle_x, 2);
  Serial.print(F(","));
  Serial.print(accel_angle_y, 2);
  Serial.print(F(","));
  Serial.print(accel_angle_z, 2);
  Serial.print(F("#GYR:"));
  Serial.print(unfiltered_gyro_angle_x, 2);        //Gyroscope angle
  Serial.print(F(","));
  Serial.print(unfiltered_gyro_angle_y, 2);
  Serial.print(F(","));
  Serial.print(unfiltered_gyro_angle_z, 2);
  Serial.print(F("#FIL:"));             //Filtered angle
  Serial.print(angle_x, 2);
  Serial.print(F(","));
  Serial.print(angle_y, 2);
  Serial.print(F(","));
  Serial.print(angle_z, 2);
  Serial.println(F(""));
  */
  
  // Delay so we don't swamp the serial port
  // delay(5);
  bool stay = true;

  Serial.print("Sent: "); 

if (angle_x < -20 || angle_x > 20) {
  stay = false;
  if (angle_x < 0) { // forward_speed
    dir = DIR_FORWARD;
    robo_speed = map(-1 * angle_x, 0, 90, 50, 250);
    constrain(angle_x, 50, 250);
  } else { // behind_speed
    dir = DIR_BACKWARD;
    robo_speed = map(angle_x, 0, 90, 50, 250);
    constrain(angle_x, 50, 250);
  }
}
if (angle_y < -20 || angle_y > 20) {
  stay = false;
  if (angle_y < 0) { // left_speed
    dir = DIR_LEFT;
    robo_speed = map(-1 * angle_x, 0, 90, 50, 250);
    constrain(angle_y, 50, 250);
  } else { // right_speed
    dir = DIR_RIGHT;
    robo_speed = map(angle_x, 0, 90, 50, 250);
    constrain(angle_y, 50, 250);
  }
} 
  if (stay == false) {
    sendDirection(dir, 250);
  } else {
    sendDirection(DIR_NONE, 0);
  }
}

//void printDirection(const byte dir) {
//  Serial.print("Sent: "); 
//  switch (dir) {
//        case FORWARD: { // forward
//          Serial.print("Forward Speed = ");
//          break;
//        }
//        case BEHIND: { // behind
//          Serial.print("Behind Speed = ");
//          break;
//        }
//        case LEFT: { // Left
//          Serial.print("Left Speed = ");
//          break;
//        }
//        case RIGHT: { // Right
//          Serial.print("Right Speed = ");
//          break;
//        }
//        default: {
//          Serial.print("NONE Speed = ");
//          Serial.println(dir);          
//          break;
//        }
//  }
//}

void sendDirection(const byte dir, const byte robotSpeed) {
//  byte massage[2];
//  massage[0] = dir;
//  massage[1] = robotSpeed;

  int massage[] = {0, 0, 0, 0};
  massage[0] = 1;
  massage[1] = 0;
  massage[2] = dir;
  massage[3] = robotSpeed;
  
  radio.write(&massage, sizeof(massage));
  
  delay(10);
  

//   const char text[] = "Hello World";
//  radio.write(&text, sizeof(text));
//  
//  delay(50);
  
//  radio.write(&massage, sizeof(massage));
  Serial.print(massage[0]);
  Serial.print(" | DIR = ");
  Serial.println(massage[2]);
//  printDirection(dir);
//  Serial.println(robotSpeed);
}

// axelerometer + gyroscope MPU-6050 dunctions 
// --------------------------------------------------------
// MPU6050_read
//
// This is a common function to read multiple bytes 
// from an I2C device.
//
// It uses the boolean parameter for Wire.endTransMission()
// to be able to hold or release the I2C-bus. 
// This is implemented in Arduino 1.0.1.
//
// Only this function is used to read. 
// There is no function for a single byte.
//
int MPU6050_read(int start, uint8_t *buffer, int size)
{
  int i, n, error;

  Wire.beginTransmission(MPU6050_I2C_ADDRESS);
  n = Wire.write(start);
  if (n != 1)
    return (-10);

  n = Wire.endTransmission(false);    // hold the I2C-bus
  if (n != 0)
    return (n);

  // Third parameter is true: relase I2C-bus after data is read.
  Wire.requestFrom(MPU6050_I2C_ADDRESS, size, true);
  i = 0;
  while(Wire.available() && i<size)
  {
    buffer[i++]=Wire.read();
  }
  if ( i != size)
    return (-11);

  return (0);  // return : no error
}


// --------------------------------------------------------
// MPU6050_write
//
// This is a common function to write multiple bytes to an I2C device.
//
// If only a single register is written,
// use the function MPU_6050_write_reg().
//
// Parameters:
//   start : Start address, use a define for the register
//   pData : A pointer to the data to write.
//   size  : The number of bytes to write.
//
// If only a single register is written, a pointer
// to the data has to be used, and the size is
// a single byte:
//   int data = 0;        // the data to write
//   MPU6050_write (MPU6050_PWR_MGMT_1, &c, 1);
//
int MPU6050_write(int start, const uint8_t *pData, int size)
{
  int n, error;

  Wire.beginTransmission(MPU6050_I2C_ADDRESS);
  n = Wire.write(start);        // write the start address
  if (n != 1)
    return (-20);

  n = Wire.write(pData, size);  // write data bytes
  if (n != size)
    return (-21);

  error = Wire.endTransmission(true); // release the I2C-bus
  if (error != 0)
    return (error);

  return (0);         // return : no error
}
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

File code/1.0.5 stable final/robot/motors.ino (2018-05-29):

void Motors_set() {
  pinMode (ENA, OUTPUT);  //ШИМ выход 1
  pinMode (IN1, OUTPUT);
  pinMode (IN2, OUTPUT);
  pinMode (ENB, OUTPUT);  //ШИМ выход 2
  pinMode (IN3, OUTPUT);
  pinMode (IN4, OUTPUT);
}

void Motors_init(byte CURR_MODE) {
   switch (CURR_MODE) {
    case Off: {
          /* Not realized! */
        break;
    }
    case HandControl: {
      IN1 = 5; // !
      IN2 = 8;
      IN3 = 7;
      IN4 = 4;
      
      ENA = 10;  // ШИМ выход 1 // !
      ENB = 6;  // ШИМ выход 2

      Motors_set();
      break;
    }
    case Detour: {
      IN1 = 12; // 12 -> 5
      IN2 = 8;
      IN3 = 7;
      IN4 = 4;
      
      ENA = 11;  //ШИМ выход 1 // !
      ENB = 6;  //ШИМ выход 2
      
      Motors_set();
     break;
    }
    case Record: {
       /* Not realized! */   
      break;
    }
    }
}

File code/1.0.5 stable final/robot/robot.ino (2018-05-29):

#include "radio.h"
#include "directions.h"
#include "detour.h"
#include "distance.h"
#include "massage.h"
#include "motors.h"
#include "modes.h"
#include "Ultrasonic.h"
#include <Servo.h>

#define SERVO_MAIN_PIN 9
Servo servo;

#define TRIGGER_PIN 14 
#define ECHO_PIN 15 
Ultrasonic main_scaner(TRIGGER_PIN, ECHO_PIN);
Ultrasonic back_scaner(A2, A3); 

void setup() {
  
  /* #HAND_CONTROL  */  
    cur_mode = HandControl;

  /* #DETOUR */
  //  cur_mode = Detour;

  while (!Serial);
  Serial.begin(9600);

  switch (cur_mode) {
    case Off: {
        /* Not realized! */
        break;
    }
    case HandControl: {
      Radio_start();    
      break;
    }
    case Detour: {
      servo.attach(SERVO_MAIN_PIN);       
      break;
    }
    case Record: {
       /* Not realized! */   
      break;
    }
  }
    
   Motors_init(cur_mode);
}

void loop() {

  if (inp_inptype == SHANGE_MODE) {
      cur_mode = inp_mode;
       /* Not realized! */
  }
  if (inp_inptype == SWITCH_OFF) {
       /* Not realized! */
  }
  if (inp_inptype == SWITCH_ON) {
       /* Not realized! */
  }
        
  switch (cur_mode) {
    case Off: {
          /* Not realized! */
        break;
    }
    case HandControl: {
      if (radio.available()) {
        int massage[] = {0, 0, 0, 0};
    
        radio.read(&massage, sizeof(massage));

        byte inp_mode = massage[0];
        byte inp_submode = massage[1];
        byte inp_inptype = massage[2];
        byte inp_speed = massage[3];

        // print data to debug
        /*
        Serial.print(inp_mode);
        Serial.print(" |  ");
        Serial.print(inp_submode);
        Serial.print(" | Direction ");
        Serial.print(inp_inptype);
        Serial.print(" |  ");
        Serial.println(inp_speed);
        */
        
        cur_direction = inp_inptype;
      
        ride(cur_direction, SPEED_MAX, 0);
      }
      break;
    }
    case Detour: {
      
     new_algorithm();
     
     break;
    }
    case Record: {
       /* Not realized! */   
      break;
    }
    }
}
